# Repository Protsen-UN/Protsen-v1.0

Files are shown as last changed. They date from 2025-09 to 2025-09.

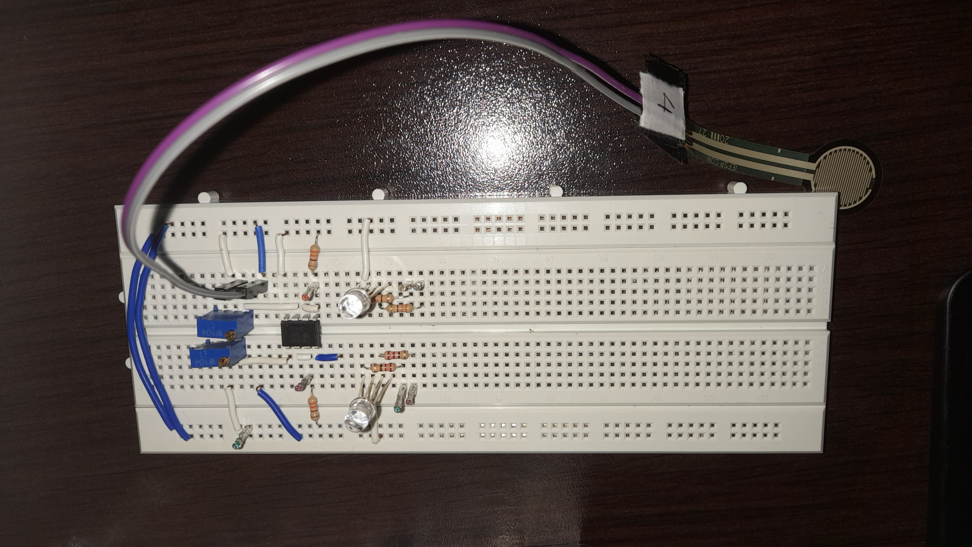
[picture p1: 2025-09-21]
Imagenes/MontajeRGB.jpg

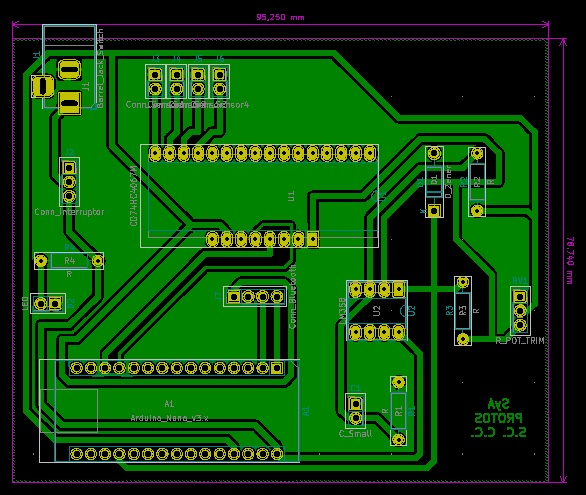
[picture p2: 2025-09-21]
Imagenes/DiseñoPCB.jpg

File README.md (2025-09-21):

# Protsen – Versión 2023

Este directorio contiene los avances y entregables del año **2023** del proyecto **Protsen**, desarrollado por el grupo estudiantil **Protos UN** de Bioingeniería en la Universidad Nacional de Colombia.

El enfoque de esta versión fue **construir y validar un sistema experimental con modelos anatómicos impresos en 3D y sensores FSR**, para analizar la presión ejercida por protuberancias óseas en un muñón.

---

## 📂 Estructura de carpetas

- **3D-Models/**  
  Contiene los modelos CAD y STL de la versión 2023.  
  - Variaciones de **cabeza del peroné (fibular head)**.  
  - Modelos de **tibia lateral y medial**.  
  - Variantes de la **tuberosidad tibial**.  
  - `Printing stump.stl`: muñón completo para impresión 3D.  
  - Archivos `.ipt` para edición paramétrica en Autodesk Inventor.  

- **Documentación/** *(si aplica)*  
  Reportes, protocolos de calibración y metodologías utilizadas en 2023.  

- **Electrónica/** *(si aplica)*  
  Esquemas, código o configuraciones empleadas para integrar los sensores FSR.  

---

## 🎯 Objetivos de la Versión 2023

- **Modelado CAD anatómico** de protuberancias óseas con diferentes dimensiones (flat, 5mm, 10mm, 15mm).  
- **Fabricación aditiva (impresión 3D)** del muñón y sus variaciones.  
- **Integración de sensores FSR** en zonas críticas del muñón.  
- **Calibración experimental** de los sensores para medir la presión.  
- **Documentación técnica** para futuras versiones del proyecto.  

---

## 🛠️ Requisitos técnicos

- **Software CAD**: Autodesk Inventor o Fusion 360 para editar `.ipt`.  
- **Impresora 3D** compatible con `.stl`.  
- **Material de impresión**: PLA / ABS recomendado.  
- **Sensores**: FSR calibrados para registrar presión.  

---

## 👩‍🔬 Grupo de investigación

Proyecto desarrollado por el grupo estudiantil **Protos UN – Bioingeniería**,  
Universidad Nacional de Colombia.  

---

## 📜 Licencia

Este proyecto se distribuye bajo la licencia **MIT**.  
Puedes usar, modificar y compartir libremente, dando el crédito correspondiente al grupo **Protos UN**.

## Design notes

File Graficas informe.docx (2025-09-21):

SENSOR 1

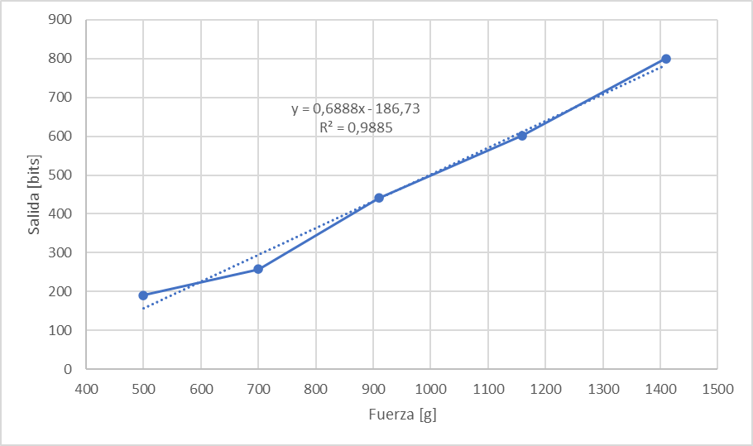
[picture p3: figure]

SENSOR 2

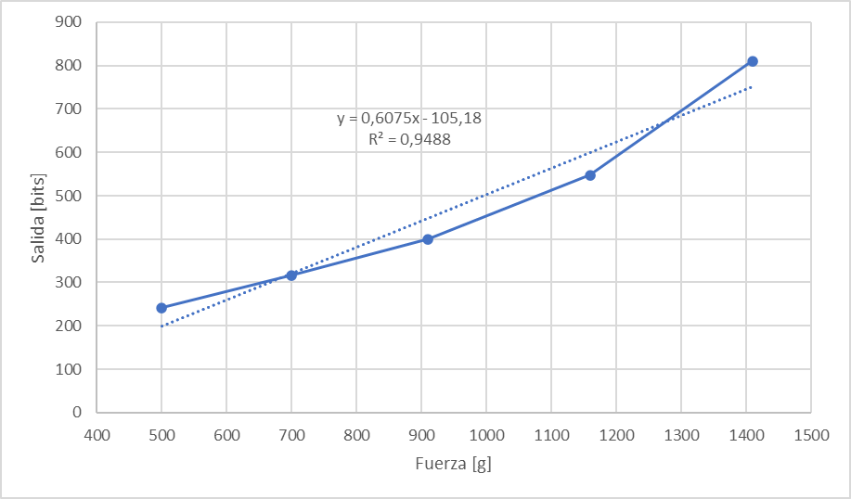
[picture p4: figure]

SENSOR 4

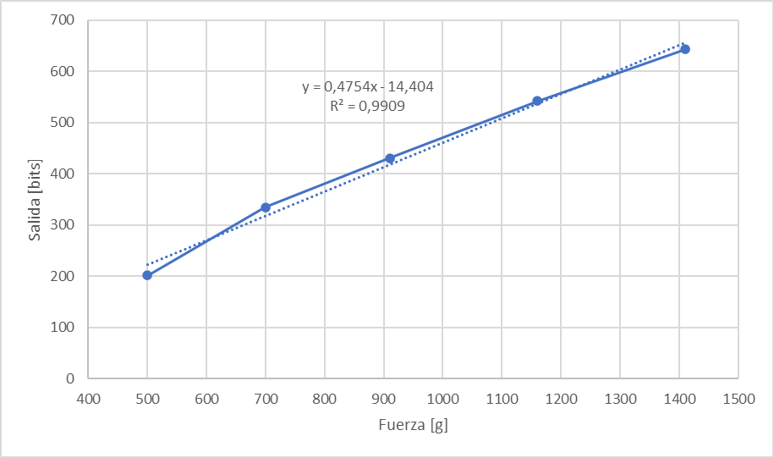
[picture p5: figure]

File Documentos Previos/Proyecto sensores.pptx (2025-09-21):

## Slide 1

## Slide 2

Proyecto Sensores

Y.F.Alpala - E.Cuadros - J.S.Daleman – N.Prieto

Ingeniería mecatrónica y mecánica
Departamento de ingeniería mecánica y mecatrónica
Facultad de ingeniería Universidad
Nacional de Colombia Bogotá,
Colombia
2023

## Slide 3

Problemática y solución

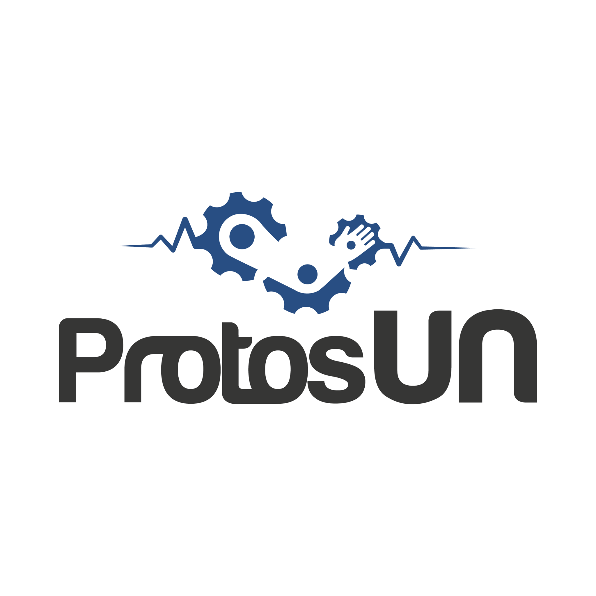
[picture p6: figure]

- Las prótesis son creadas de forma genérica por lo que al no acoplarse perfectamente al muñón pueden crear incomodidades.
- Es necesario modificar las prótesis para evitar que le tallen al usuario.
- Se plantea un sistema que detecte las fuerzas ejercidas sobre el muñón para facilitar su adaptación al usuario.

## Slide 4

Elementos necesarios

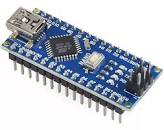
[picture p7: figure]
Arduino Nano Atmega Mini Usb V3.0
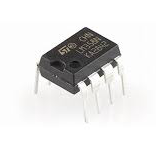
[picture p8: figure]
LM358 Amplificador Operacional lm358 Circuito Integrado – Arca Electrónica
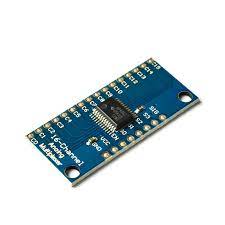
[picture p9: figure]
Modulo Multiplexor Digital/Analógico 16 Canales CD74HC4067 - Electronilab
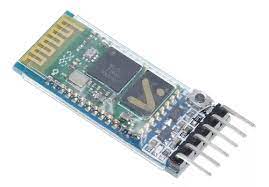
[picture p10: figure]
Modulo Transceptor Rf Bluetooth Hc-05 Arduino Pic Otros
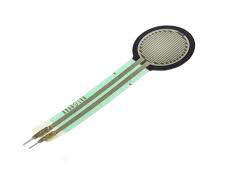
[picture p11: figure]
SENSOR DE FUERZA RESISTIVO FSR402
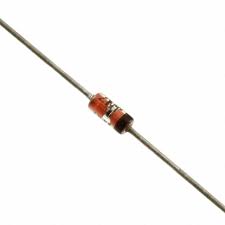
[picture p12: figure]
1N4931 Microchip Technology | Productos semiconductores discretos | DigiKey

Facultad Ancízar Sans Itálica 9 pt
Sede Ancízar Sans Itálica 9 pt

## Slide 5

Circuito electrónico

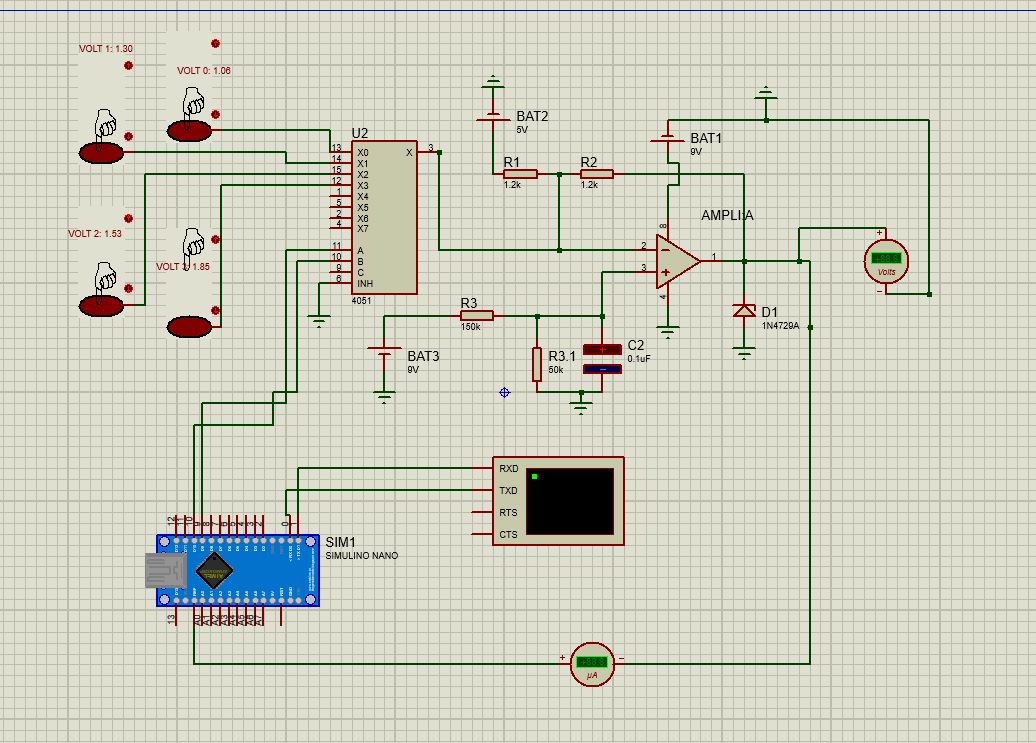
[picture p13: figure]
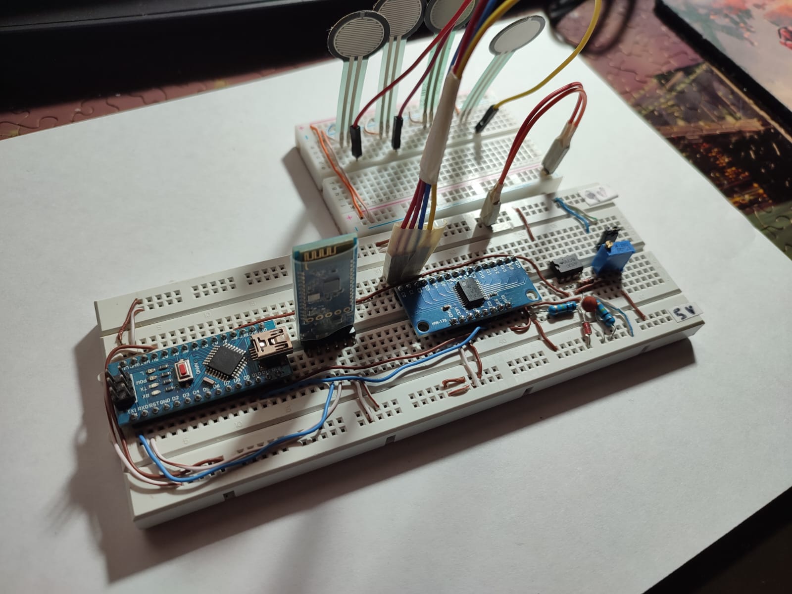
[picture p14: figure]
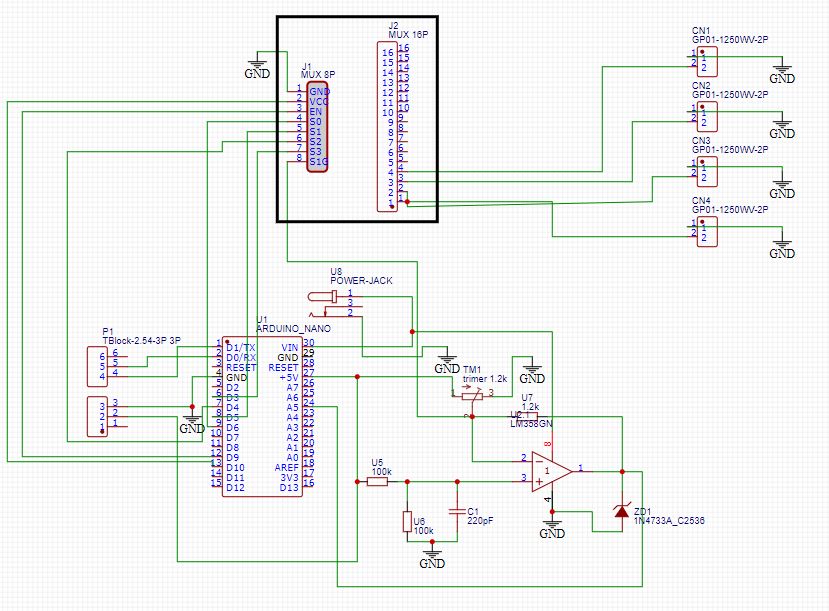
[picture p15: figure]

Facultad Ancízar Sans Itálica 9 pt
Sede Ancízar Sans Itálica 9 pt

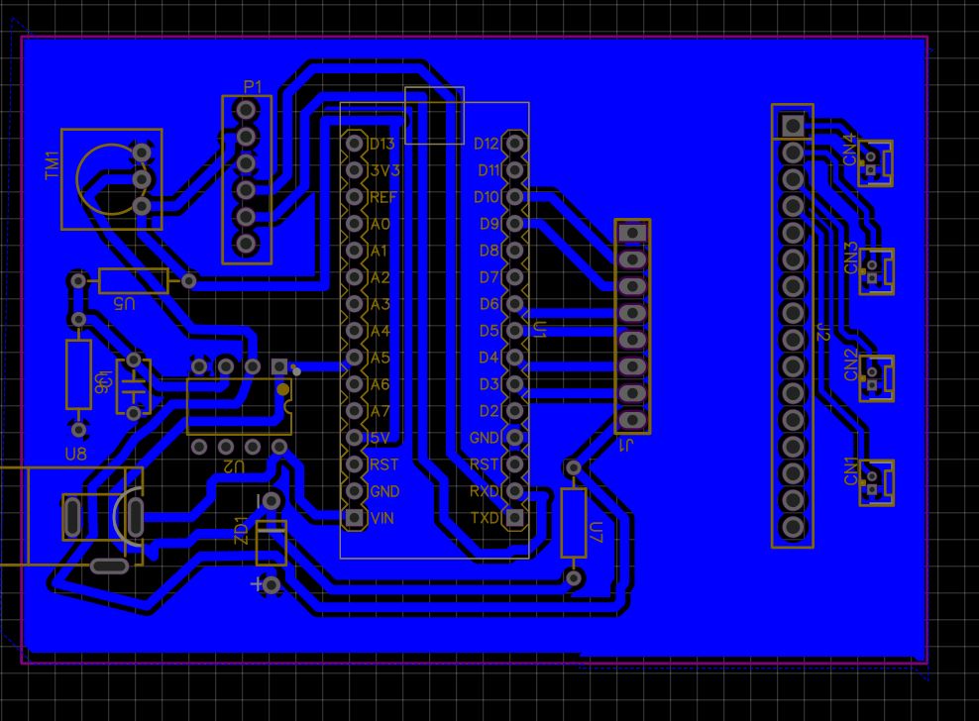
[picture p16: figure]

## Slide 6

Interfaz grafica

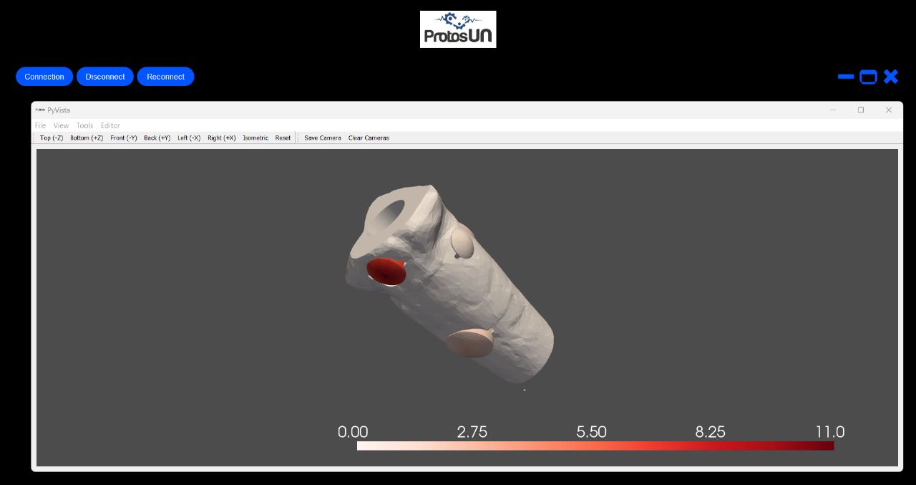
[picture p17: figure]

Facultad Ancízar Sans Itálica 9 pt
Sede Ancízar Sans Itálica 9 pt

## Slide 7

Referencias
[1] “Ajuste psicosocial en pacientes amputados: La psicolog ́Ia en el contexto sanitario.”https://www.binasss.sa.cr/bibliotecas/bhp/cupula/v31n2/art02.pdf ,
consultado: 2023-06-28.
[2] V. A, USO DE SENSORES DE FUERZA RESISTIVOS PARA MEJORAR LA COMODIDAD EN PR ́OTESIS PARA EXTREMIDADES DE ANIMALES. UNIVERSIDAD SAN FRANCISCO DE QUITO USFQ, 2021.
[3] “Fsr 402 datasheet,” https://www.trossenrobotics.com/productdocs/2010-10-26-DataSheet-FSR402-Layout2.pdf, consultado: 2023-05-08.

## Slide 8

Gracias

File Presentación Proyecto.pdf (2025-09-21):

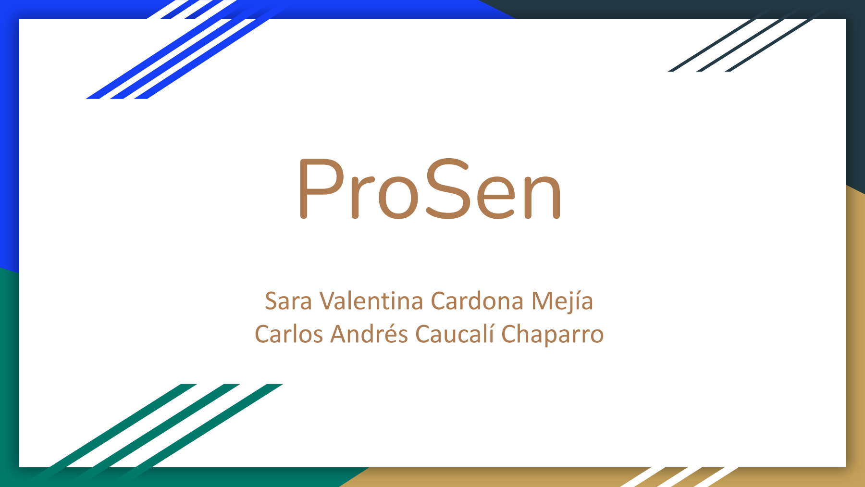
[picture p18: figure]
ProSen; Sara Valentina Cardona Mejía Carlos Andrés Caucalí Chaparro

# Planteamiento

- Continuación del proyecto de Protos UN → Medición de la presión en ciertos puntos en un modelo 3D de un muñón de pierna para simular la presión que ejerce una prótesis de pierna sobre el muñón.

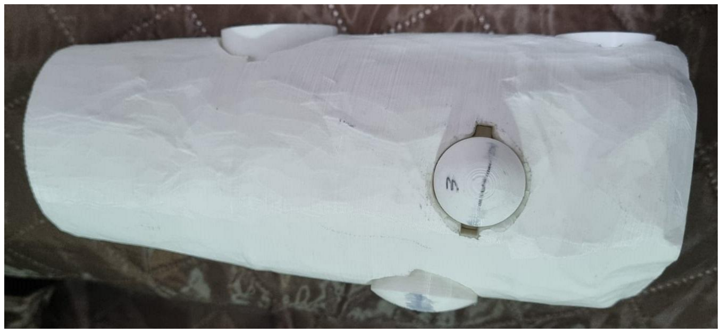
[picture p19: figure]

- Circuito en protoboard.
- Modelo 3D del muñón.
- Programa de la interfaz.

# Propuesto vs Logrado

- Diseño e implementación del circuito en una PCB.
- Calibración de los sensores en el muñón.
- Implementación de la información obtenida de la calibración en la interfaz gráfica del modelo 3D del muñón (comunicación en tiempo real de lo obtenido por los sensores con el
modelo | 3D | para | su | correcta
visualización).
- Diseño e implementación de una PCB, sin embargo, el tamaño se puede reducir.
- Calibración de los sensores, sin embargo, el procedimiento no fue el más adecuado.
- Implementación de la información obtenida de la calibración en la interfaz gráfica del modelo 3D del muñón, sin embargo, la comunicación en tiempo real presentó problemas.

# Problemas y Retos Presentados

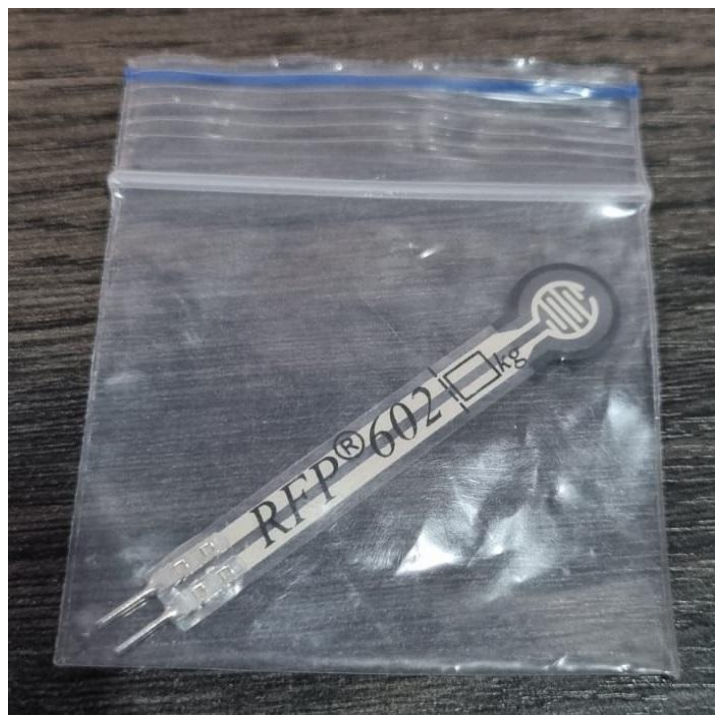
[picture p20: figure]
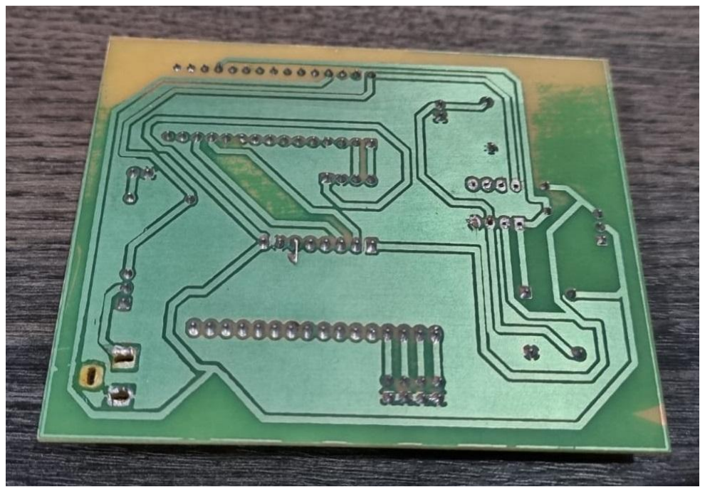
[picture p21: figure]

- La PCB quedó mal diseñada.
- El sensor RFP602 no funcionó.
- | La | lectura | de | los | canales | del
multiplexor presentó errores.
- El procedimiento para la calibración no fue el más adecuado.
- La comunicación por medio de bluetooth con el programa para generar la interfaz no fue efectiva.

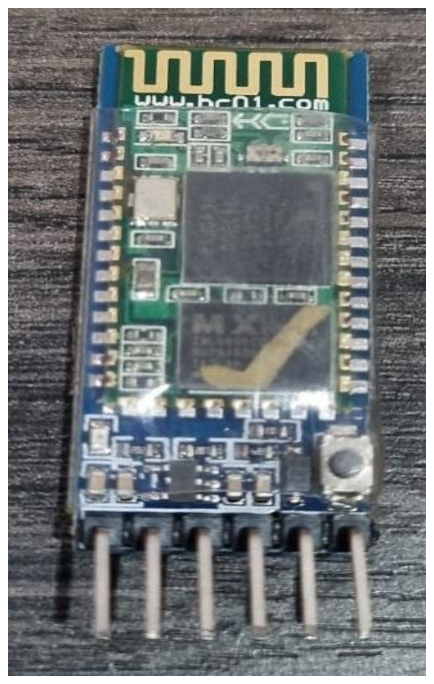
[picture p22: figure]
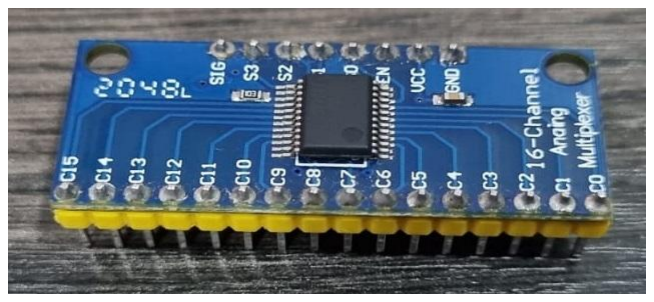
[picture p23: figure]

# PCB

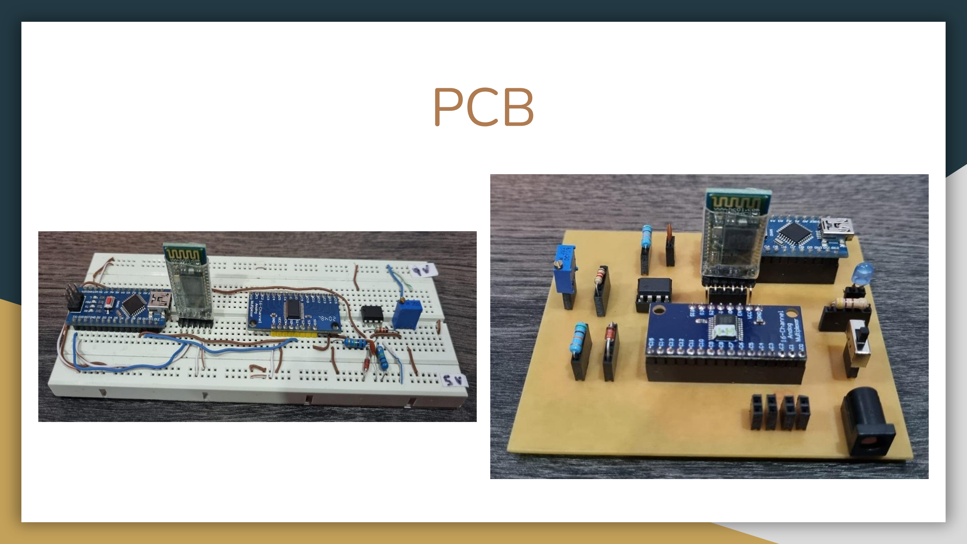
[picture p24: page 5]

# Calibración

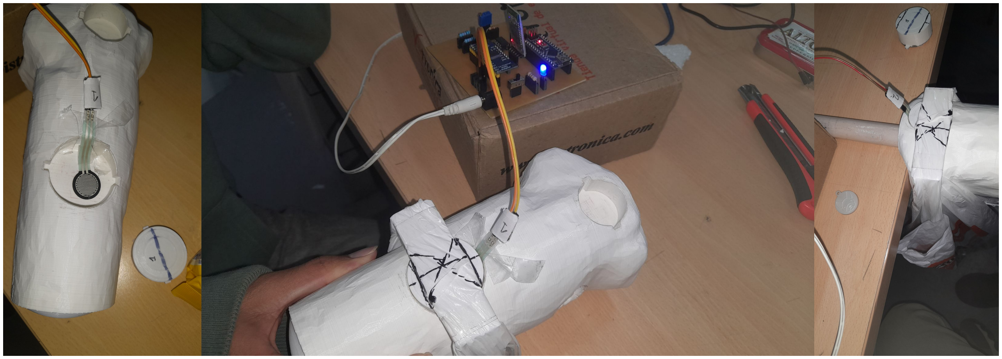
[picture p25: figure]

# Calibración

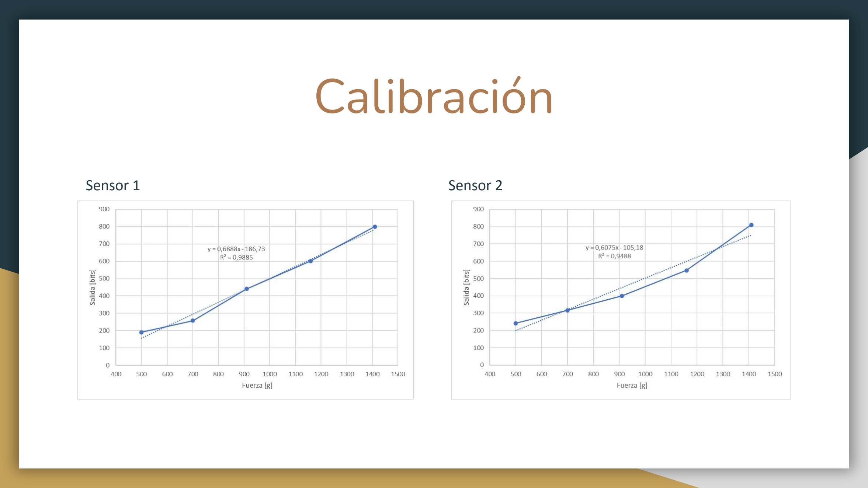
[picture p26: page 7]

Sensor 1 | Sensor 2

# Calibración


Sensor 3 | Sensor 4

# Interfaz


# Interfaz


# Montaje Circuito con RGB


20 N

0 N

# Costos

Implemento | Precio (COP)
PCB | $50.000
Componentes electrónicos | $50.000
Cable Arduino | $8.000
Papelería | $5.000
Total | $113.000

# A futuro…


- Reducir el tamaño de la PCB y añadir más sensores.
- Rediseñar el modelo 3D del muñón para realizar de manera correcta la calibración de los sensores.
- Revisar la comunicación en tiempo real de lo obtenido por los sensores con la interfaz.

# Gracias

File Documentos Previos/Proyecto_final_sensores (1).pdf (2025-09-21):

# Sistema de lectura de puntos de presion para ´

adecuacion de pr ´ | otesis de pierna ´

1

st Juan Sebastian Daleman Martinez
Universidad Nacional de Colombia Bogota, Colombia
jdaleman@unal.edu.co

2

nd Nicolas Prieto ´
Universidad Nacional de Colombia Bogota, Colombia
nprietos@unal.edu.co

3

rd Yuli Fernanda Alpala
Universidad Nacional de Colombia Bogota, Colombia
yalpalac@unal.edu.co

4

th Eduardo Cuadros Montealegre
Universidad Nacional de Colombia Bogota, Colombia
ecuadrosm@unal.edu.co
I. RESUMEN
En este trabajo, se presenta el desarrollo de un sistema de monitoreo de fuerzas portatil que utiliza sensores de fuerza ´ resistivos (FSR). El sistema incluye una interfaz de usuario que muestra en tiempo real un modelo 3D del munõn, donde se ´ representan las fuerzas aplicadas mediante un mapa de calor. Este enfoque permite obtener informacion precisa y detallada ´ sobre las fuerzas ejercidas en el munõn durante el uso de ´ protesis. Al visualizar las fuerzas en el modelo 3D, se pueden ´
identificar areas de alta presi ´ | on y evaluar como var ´ | ían las
fuerzas en diferentes situaciones. Esta informaci ´ | on es esencial ´
para mejorar el diseno mec ˜ | anico de la pr ´ | otesis y lograr una ´
distribucion m ´ | as equilibrada de las fuerzas, reduciendo as ´ | í los
problemas de incomodidad y las posibles lesiones cutaneas. ´
Index Terms—FSR, Protesis, Z ´ | ocalo, Mu ´ | nõn, Interfaz, Sensores, ´
Fuerzas.

II. INTRODUCCION´

En la actualidad, las amputaciones de extremidades son una realidad en muchas personas de todo el mundo, estas representan un desafío significativo para la calidad de vida de las personas que lo experimentan. A menudo se requiere es
uso de las protesis para proporcionar una soluci ´ | on importante ´
para mejorar la funcionalidad y el bienestar de los individuos afectados. [1] Sin embargo, aunque se han proporcionado avances en la tecnología de protesis, muchos usuarios ´ experimentan problemas de incomodidad y dolor debido a
la mala distribucion de fuerzas en el z ´ | ocalo de la pr ´ | otesis. ´
Debido a esto se presentan diversos inconvenientes, como lesiones cutaneas, infecciones y otras complicaciones que ´ afectan negativamente la experiencia de los usuarios. [1]

Para abordar esta problematica, es necesario desarrollar ´
un monitoreo de fuerzas entre el zocalo de la pr ´ | otesis y el ´
munõn residual. Este sistema permitir ´ | ía extraer informacion´
valiosa para mejorar el diseno mec ˜ | anico de la pr ´ | otesis y ´
lograr un ajuste adecuado. Si se obtienen datos precisos sobre las fuerzas ejercidas en el munõn durante el uso de la ´
protesis, se puede evaluar de manera objetiva la distribuci ´ | on´
de fuerzas y detectar posibles puntos de presion excesiva o ´
areas problem ´ | aticas. Lo anterior es de gran importancia para ´

prevenir lesiones cutaneas, minimizar el dolor y mejorar la ´ comodidad general de los usuarios de protesis. ´

La importancia de mejorar el ajuste del encaje protesico ´ debe ser de gran importancia, pues esta tiene un impacto en la calidad de vida, la salud y el bienestar de las personas con amputaciones. Los encajes mal ajustados limitan la capacidad funcional y la participacion en actividades diarias. ´ Por ello, es crucial que se dediquen esfuerzos significativos para desarrollar enfoques innovadores que aborden este desafío clínico y mejoren la calidad de vida de las personas con amputaciones. Así pues, en este trabajo se presenta un prototipo de sistema de monitoreo de fuerzas portale, ´ utilizando sensores de fuerza resistivos, este cuenta con interfaz de usuario que muestra en tiempo real, un modelo
3D del munõn, las fuerzas aplicadas sobre ´ | este mediante ´
un mapa de calor, permitiendo así un analisis en periodos ´
de tiempos largos, el prototipo sera aplicado a la pr ´ | otesis ´
desarrollada por el grupo de investigacion ProtosUN de la ´ Universidad Nacional de Colombia.

III. MARCO TEORICO ´

A. Sensores FSR
Los sensores FSR son dispositivos usados comunmente para ´
la medicion de presi ´ | on o fuerza aplicada a una superficie (ver ´
Figura 1). Dichos sensores estan compuestos por una capa ´ delgada de material resistivo sensible a la presion que se ´ encuentra entre dos electrodos. Cuando se aplica una fuerza sobre el sensor, la capa resistiva se comprime y provoca un cambio en su resistencia electrica, la cual se puede medir para ´ hallar la magnitud de la fuerza aplicada.
B. Arduino
Arduino (ver Figura 2) es una plataforma de desarrollo tanto de software como de hardware. Esta compuesto por un microcontrolador y una placa de circuito impreso que permite programar dicho microcontrolador y así manejar dispositivos electronicos de manera sencilla. Para este nos basamos en el ´ diseno encontrado en [2] ˜


Figure 1: Sensor FSR


Figure 2: Arduino Nano

C. Interfaz en python

Python es un lenguaje de programacion de alto nivel y ´
facil de usar, adem ´ | as cuenta con una amplia variedad de ´
bibliotecas y frameworks que aumentan sus posibilidades.
1) PyVista: Usada para visualizacion y an ´ alisis de datos en ´ 3D.
2) PyQt5: Desarrollo de interfaz grafica donde se presenta ´ la figura 3D.
3) NumPy: Manejo de todo lo relacionado con operaciones matematicas y matrices. ´
4) Serial: Manejo y comunicacion con el puerto serial del ´ arduino.

IV. METODOLOGÍA

A. Circuito electronico ´

Para el acople de los sensores FSR con el arduino era
necesario acondicionar adecuadamente la senal adem ˜ | as de al ´
limitarse que se deseaba usar un solo modulo de ADC para usar la menor cantidad de recursos del arduino y necesitar un solo circuito de acondicionamiento. Se implemento un multeplexor para seleccionar la senal que es sensada, un ˜ amplificado operacional para acondicionar la senal y un diodo ˜ zener como proteccion de la entrada del arduino.(Ver figura 3) ´


Figure 3: Circuito de acondicionamiento de la senal . ˜

EL amplificador operacional es un LM358 en una configu-racion de restador, las resistencia R1 se implemento como un ´ trimmer para la calibracion del circuito para obtener el mejor ´ punto de operacion posible. El multiplexor es un HP4067 el ´ cual permite recorrer uno por uno los sensores e ir midiendo sus valores. Se tiene el diodo zener que es un 1N4729 que
sirve para tener una tension en la salida m ´ | axima en la entra ´
del arduino de 5V y cualquier corriente anomala sea rechazada ´ por la entrada del arduino. Por ultimo un modulo Tx-Rx el cual en la implementacion se coloco como un modulo bluetooth hc- ´
05 para hacer la conexion con el computador que recibir ´ | a los ´
datos como se puede ver mejor en la figura 4.


Figure 4: Circuito de acondicionamiento de la senal implementado en una ˜ protoboard.

B. Programacion arduino ´
Para el desarrollo del codigo se destino que se usar ´ | ían 4
sensores para esto el multiplexor solo necesita dos pines de control, se usaria el ADC del aduino por el PIN A0 y los datos se transmitirían al computador por comunicacion serial. ´ Ademas de que los datos se van almacenando en una cadena ´

de texto la cual es transmitida cada segundo.

El codigo final se dividi ´ | o en dos partes uno usado para ´
la calibracion de cada sensor y otro que seria el de ´ funcionamiento donde se muestrean todos los sensores y se envía la informacion. ´


Figure 5: Programa implementado en el arduino Nano.

C. Calibracion de sensores RFS ´
Para la calibracion de los sensores RFS primero se ´ acomodo el cero del circuito al mejor punto posible siendo este punto en un valor de bits 260, luego teniendo en cuenta que el fabricante de los sensores dice que estos operan entre un rango de 0-12N. Esta fuerza podría generar se al colocar sobre una superficie plana y horizontal 1.2 Kg, por lo cual se hicieron 12 bolsas de arroz cada uno con un peso de 100 gramos (los patrones se hicieron usando una gramera) para lograr el peso completo. [3]

Por ultimo se experimento con cada sensor poniendo ascendentemente los pesos y luego descendente. Por ultimo se hicieron pruebas aleatorias con los pesos obteniendo un comportamiento lineal como lo indica el fabricante pero con un rango de 11N solamente. Siendo la curva ideal una muy buena aproximacion para estos sensores. ´

D. Desarrollo interfaz grafica ´
La interfaz grafica esta dividida por tres partes: la barra ´ de conexion, la barra de acciones y un mapa de calor sobre ´ el modelo del munõn en donde se encuentran los sensores ´ distribuidos (ver figura 6).
Para la parte de conexion de se creo un c ´ | odigo el cual ´
verifica los puertos bluethoot utilizados en el computador y verifica en cada uno hasta encontrar uno que tengo un frame de datos ”Sensor1:”, si no encuentra ninguno desplegara un mensaje para el usuario de error de conexion. Al encontrar el ´ dispositivo guarda los datos en listas y los organiza para su posterior uso.

Para la parte del mapa de calor se creo un programa que modifica los valores de malla de un archivo .STL como base y segun los datos que reciba de la conexion ira ´ actualizando la grafica mostrada al usuario. ´

Para la barra de acciones de usuario se crearon botones para ampliar, cerrar y minimizar la pantalla.


Figure 6: Interfaz grafica obtenida con dos ventanas independientes. ´

E. Plano para PCB
Una vez se termino el circuito y se prob ´ | | o en protoboard, se ´
hizo el diseno y la posterior fabricaci ˜ | | on del circuito impreso. ´
En cuanto al diseno se us ˜ | o el programa EasyEDA. ´

Disenando el plano se tuvieron ciertas dificultades con ˜
la organizacion, ya que la placa deb ´ | | ía tener el menor tamanõ
posible. Teniendo en cuenta esto, se decidio cambiar un poco ´ el codigo en Arduino para ahorrar distancias en los buses. De ´ esta manera, la salida del amplificador ya no llegaría al pin
A0 del Arduino, sino al A5. Tambien se decidi ´ | o usar el pin ´
D10 como salida de 5 V para la alimentacion del multiplexor, ´
ya que este no consume m ´ | as de ´ | 100mA (capacidad maxima ´
para pines digitales del Arduino). El resultado del diseno se ˜ puede ver en la Figura 7.


Figure 7: Esquematico de circuito impreso ´

V. RESULTADOS
Como ya se establecio durante la introducci ´ | on de este ´
informe, el objetivo principal era la creacion de un sistema ´ que midiera las fuerzas ejercidas por el zocalo sobre el ´ munõn, objetivo que fue cumplido en su totalidad con los ´ requisitos propuestos por el grupo de investigacion, logrando ´ una calibracion de sensores exitosa con mediciones que ´
presentan buena precision. En la secci ´ | on de desarrollo se ve ´
el cumplimiento de los objetivos adicionales correspondientes a realizar una interfaz que resulte entendible para gente sin
conocimiento en el area de la ingenier ´ | ía, haciendo que esta
sea mas visual y entendible mediante la muestra del modelo
3d del munõn, de manera adicional, la PCB dise ´ | nada tambi ˜ | en´
cumple con el requerimiento de tamano ya que cabe dentro ˜ de orificio creado para el modelo real del munõn. ´

Como resultados para aprendizaje del grupo, se tiene un mejor entendimiento en el proceso de calibracion de sensores y ´ practica en el diseno de sistemas que permitan el uso de varios ˜ de estos, se vio de manera mas practica la adquisicion de datos ´
para multiples sensores mediante un Arduino. Se aprendi ´ | ó
sobre la integracion y comunicaci ´ | on de datos entre los dis- ´
positivos usando la comunicacion serial de Arduino fuera de ´ su software propio y sobre las dificultades de la creacion de ´
interfaces graficas que implementen la visualizaci ´ | on de datos ´
en 3d actualizada de manera constante.

VI. MEJORAS POSIBLES

- Crear un circuito completo que no use modulos sino ´ solo elementos SMD (un chip CC2540 para transmision´ bluetooth con su circuito de funcionamiento, un LM358 SMD, el multiplexor HP4067 que este integrado en la PCB) y cambiar el arduino por un microcontrolador
mas peque ´ | no que tenga los recusos necesarios (4 salidas ˜
digitales, 1 ADC y pines RX y TX).
- Uso de una bateria de polimero de litio recargable con su circuito de potencia para autonomía del circuito.
- incluir botones de reset y encedido/apagado
- Aumentar el numero de sensores usados de 4 a 8 o dado ´ el caso incluso a los 16 que soporta el multiplexor
- Integracion de las dos ventanas de la interfaz gr ´ | afica ´
- Crear una barra de menu donde puedan verse gr ´ | aficas de ´
las fuerzas cambiando en el tiempo.
- Mejorar la parte estetica de la interfaz gr ´ | afica. ´

VII. CONLUSIONES
- El desarrollo e implementacion de un sistema de mon- ´ itoreo continuo y en tiempo real de las fuerzas en una
protesis para extremidades inferiores es una contribuci ´ | | | | | | on´
significativa para mejorar la calidad de vida de los usuarios de protesis. ´
- La implementacion de una forma gr ´ | afica para mostrar los ´
datos tomados de sensores permite que la informacion´ pueda ser entendida mas facilmente por diferentes tipos ´ de usuarios.

REFERENCES

[1] “Ajuste | | psicosocial | en | | pacientes | amputa-
dos: | La | psicologÍa | en | el | contexto | sanitario.”
https://www.binasss.sa.cr/bibliotecas/bhp/cupula/v31n2/art02.pdf | ,
consultado: 2023-06-28.
[2] V. A, USO DE SENSORES DE FUERZA RESISTIVOS PARA MEJORAR LA COMODIDAD EN PROTESIS PARA EXTREMIDADES DE ANI- ´ MALES. UNIVERSIDAD SAN FRANCISCO DE QUITO USFQ, 2021.
[3] “Fsr 402 datasheet,” https://www.trossenrobotics.com/productdocs/2010-10-26-DataSheet-FSR402-Layout2.pdf, consultado: 2023-05-08.

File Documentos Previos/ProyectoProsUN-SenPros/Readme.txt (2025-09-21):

Solo es necesario tener el dispossitivo conectado al PC y ejecurar el .exe

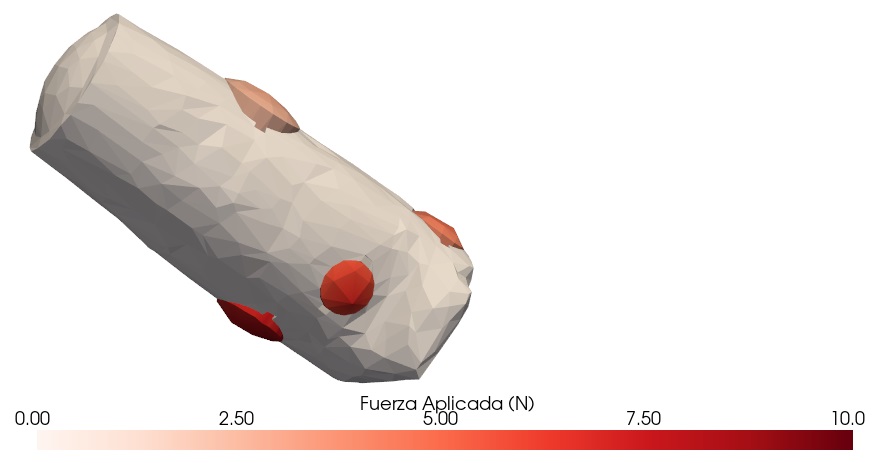
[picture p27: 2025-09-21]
Imagenes/Modelo3D.jpg

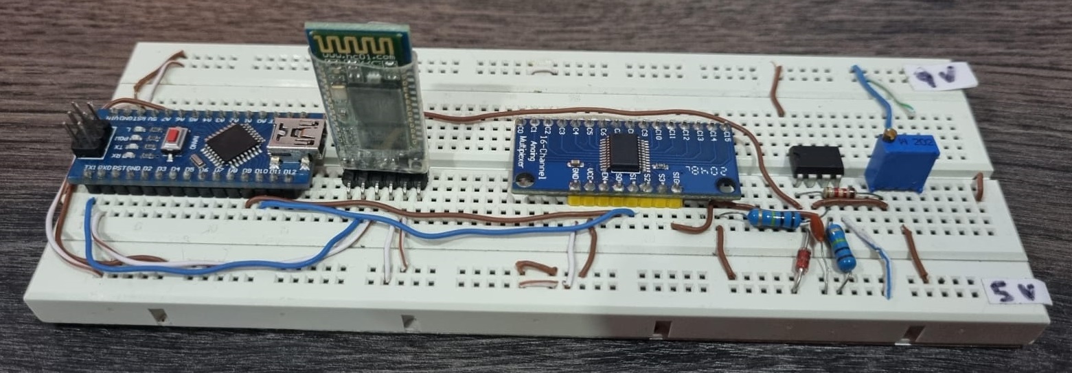
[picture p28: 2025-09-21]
Imagenes/CircuitoProtoboard.jpeg

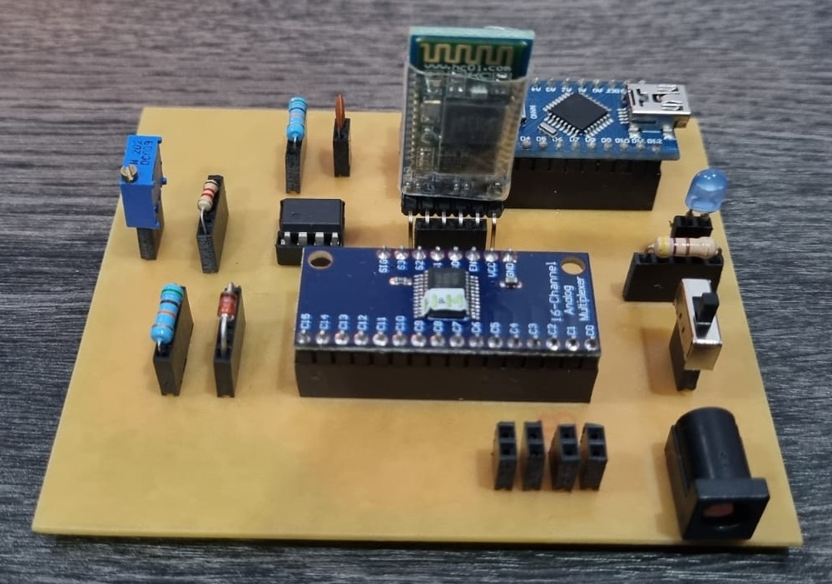
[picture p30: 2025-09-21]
Imagenes/CircuitoPCB.jpeg

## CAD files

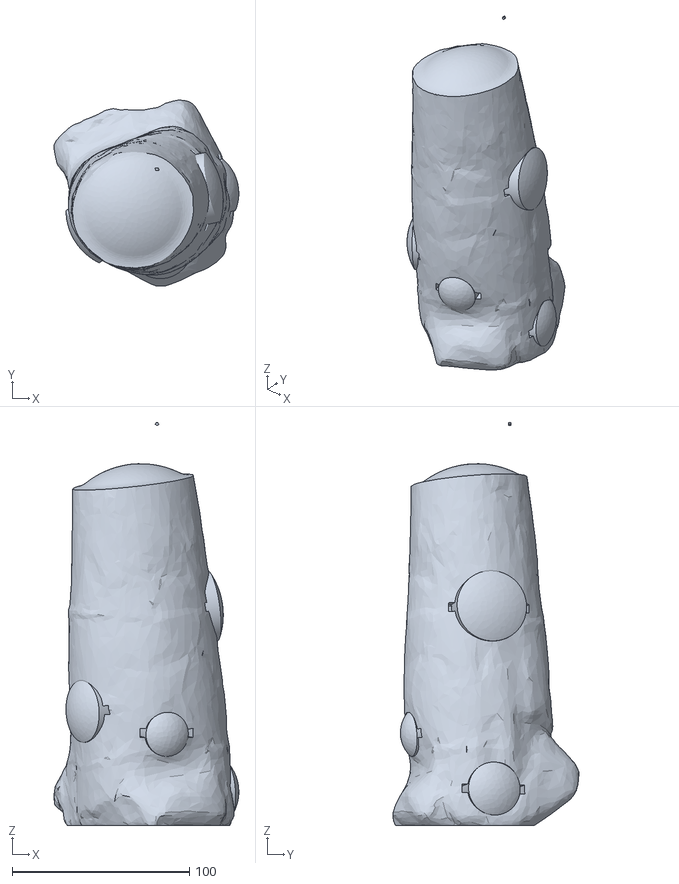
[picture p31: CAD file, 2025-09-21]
Documentos Previos/ProyectoProsUN-SenPros/MallaSimpl.stl
104.2 x 105.0 x 227.4

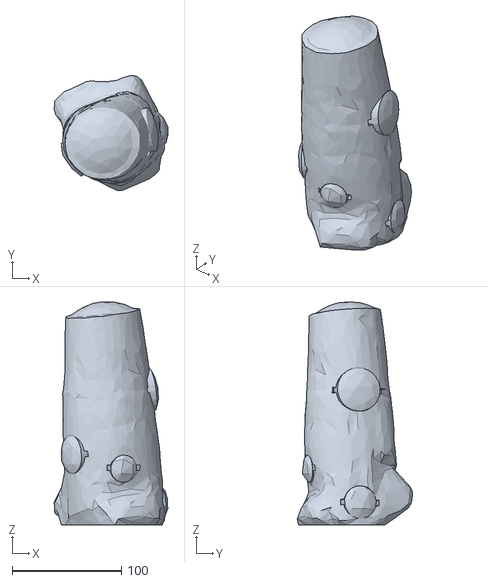
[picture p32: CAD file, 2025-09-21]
Interfaz Final/Sources/MallaSTL-sept1.stl
104.0 x 105.7 x 204.1

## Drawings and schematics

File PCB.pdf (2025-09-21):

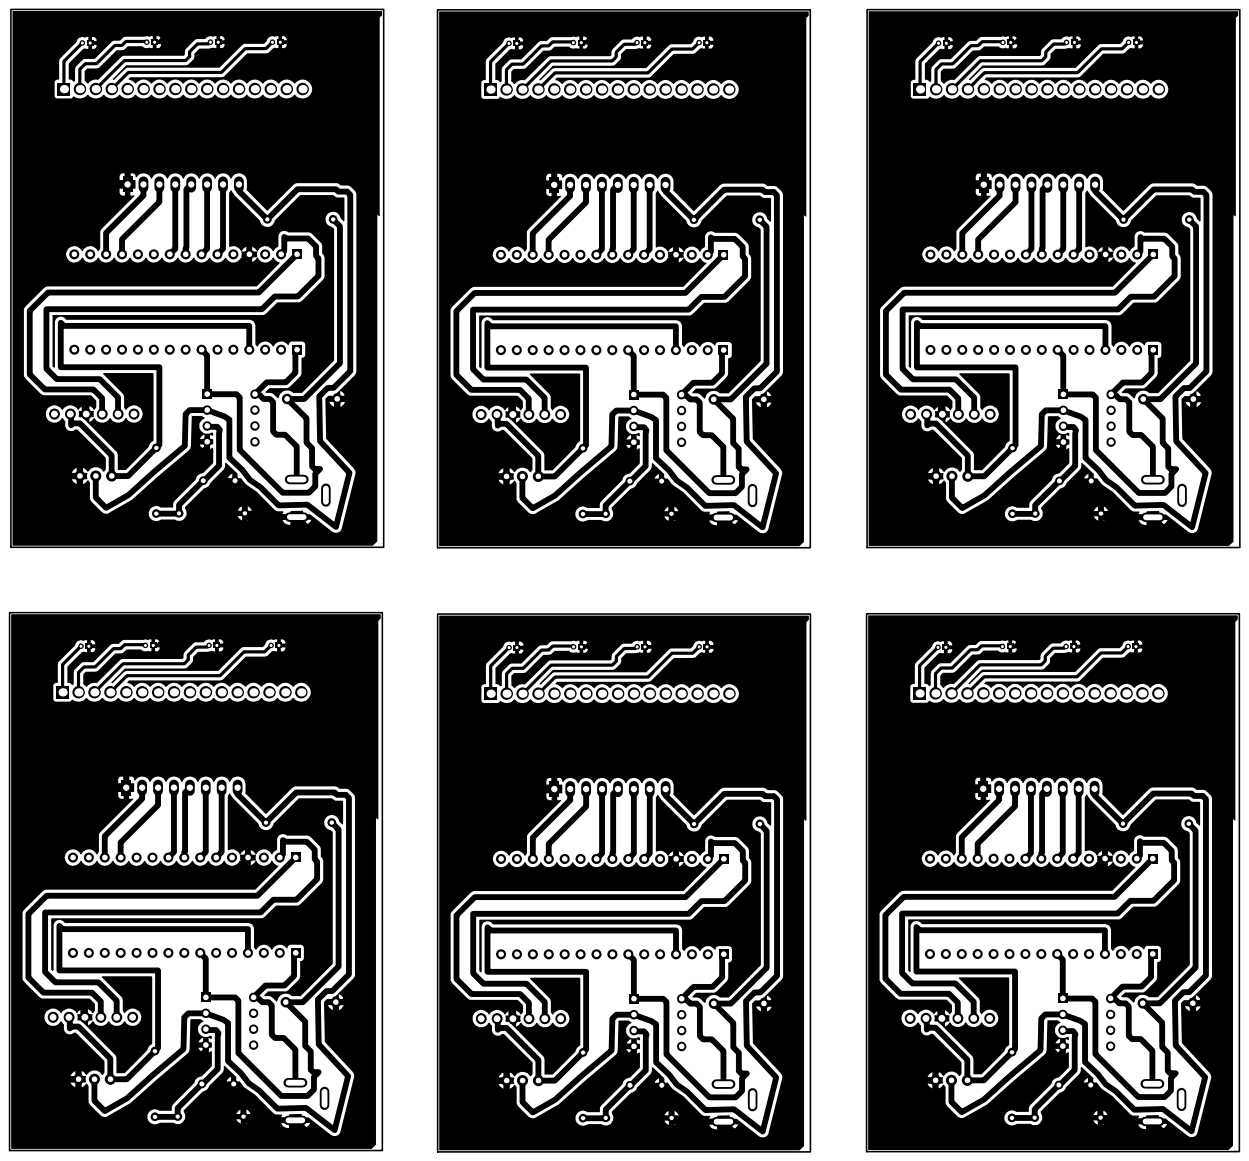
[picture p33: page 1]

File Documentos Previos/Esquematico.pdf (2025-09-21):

10 10 11 11 12 12 13 13 14 14 15 15 16 16

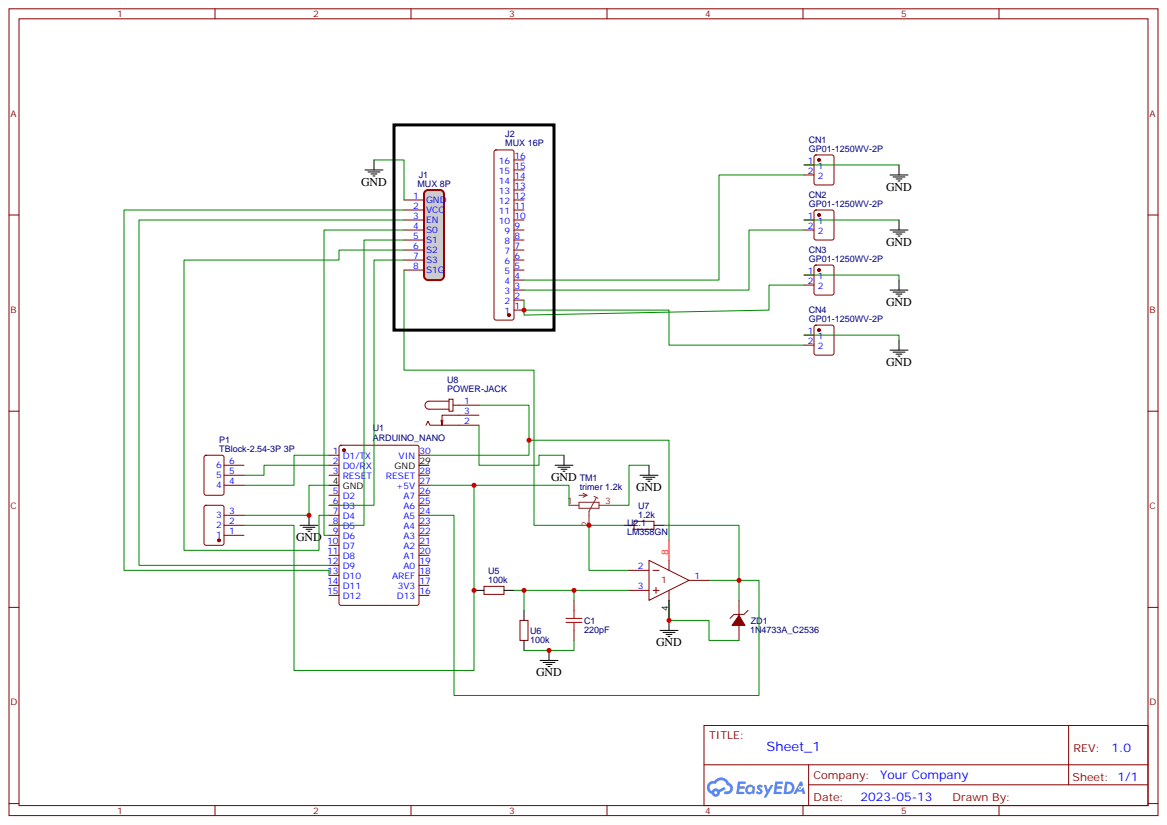
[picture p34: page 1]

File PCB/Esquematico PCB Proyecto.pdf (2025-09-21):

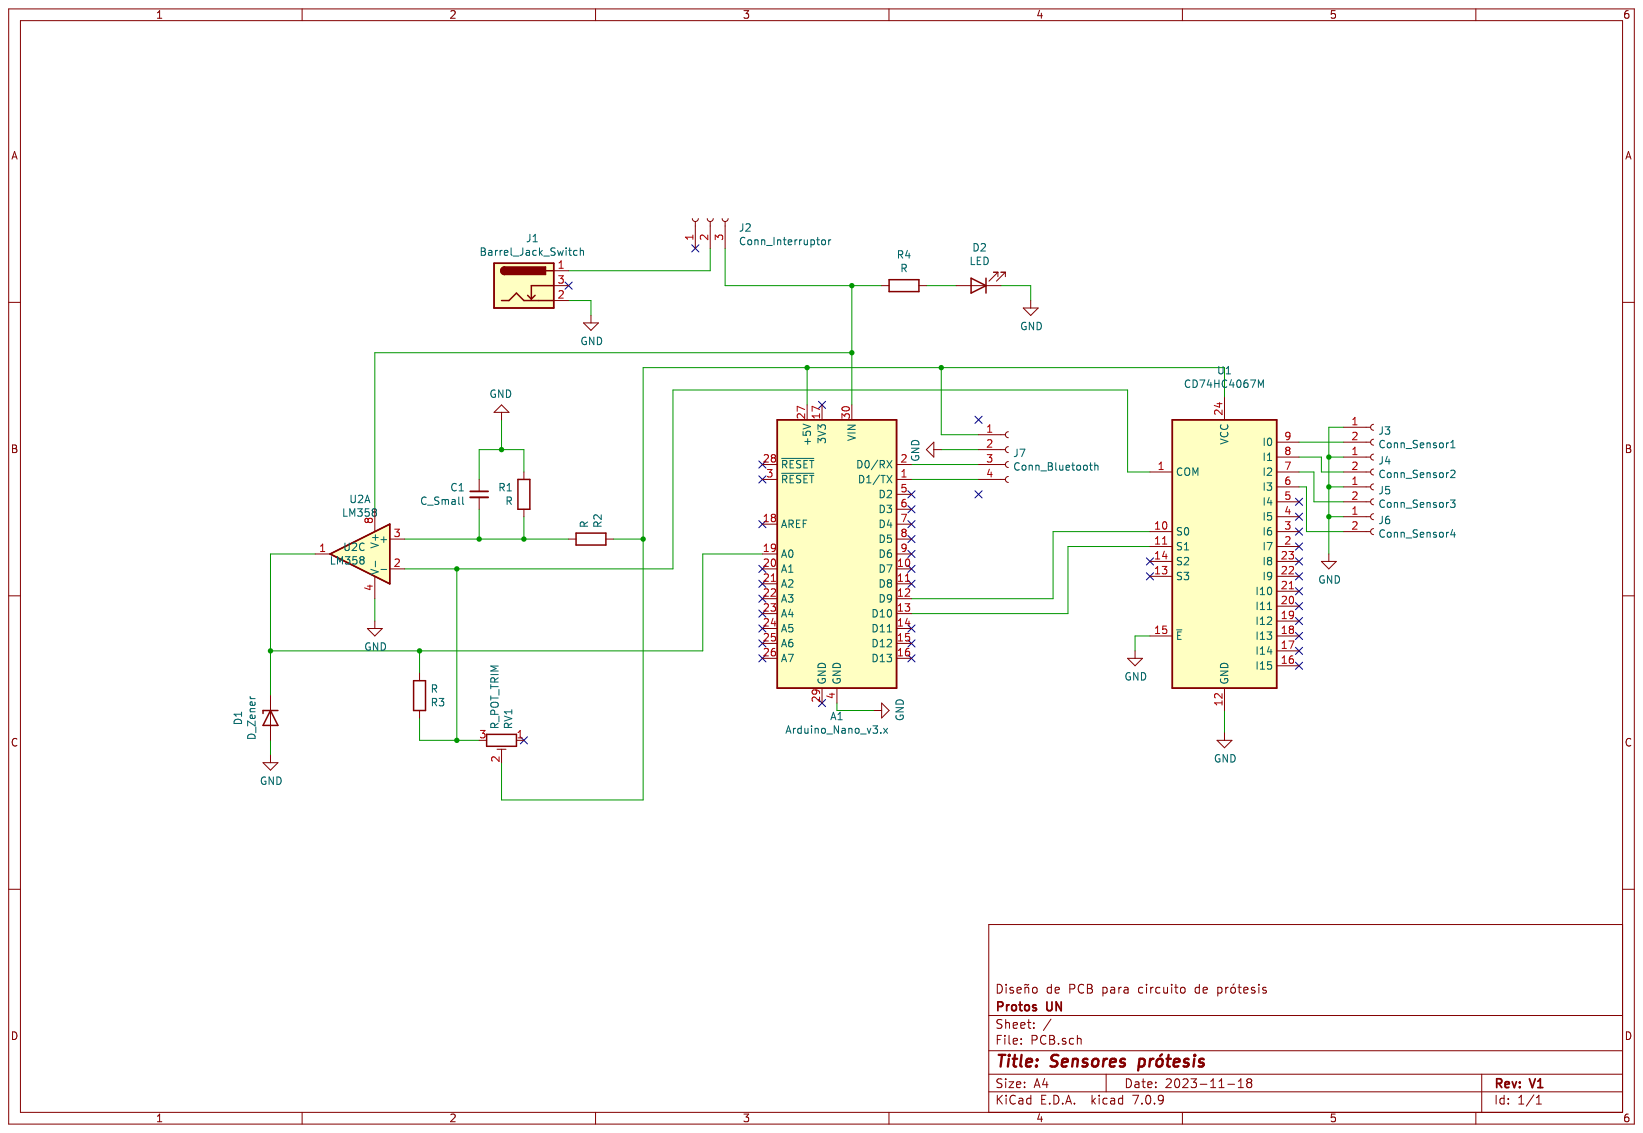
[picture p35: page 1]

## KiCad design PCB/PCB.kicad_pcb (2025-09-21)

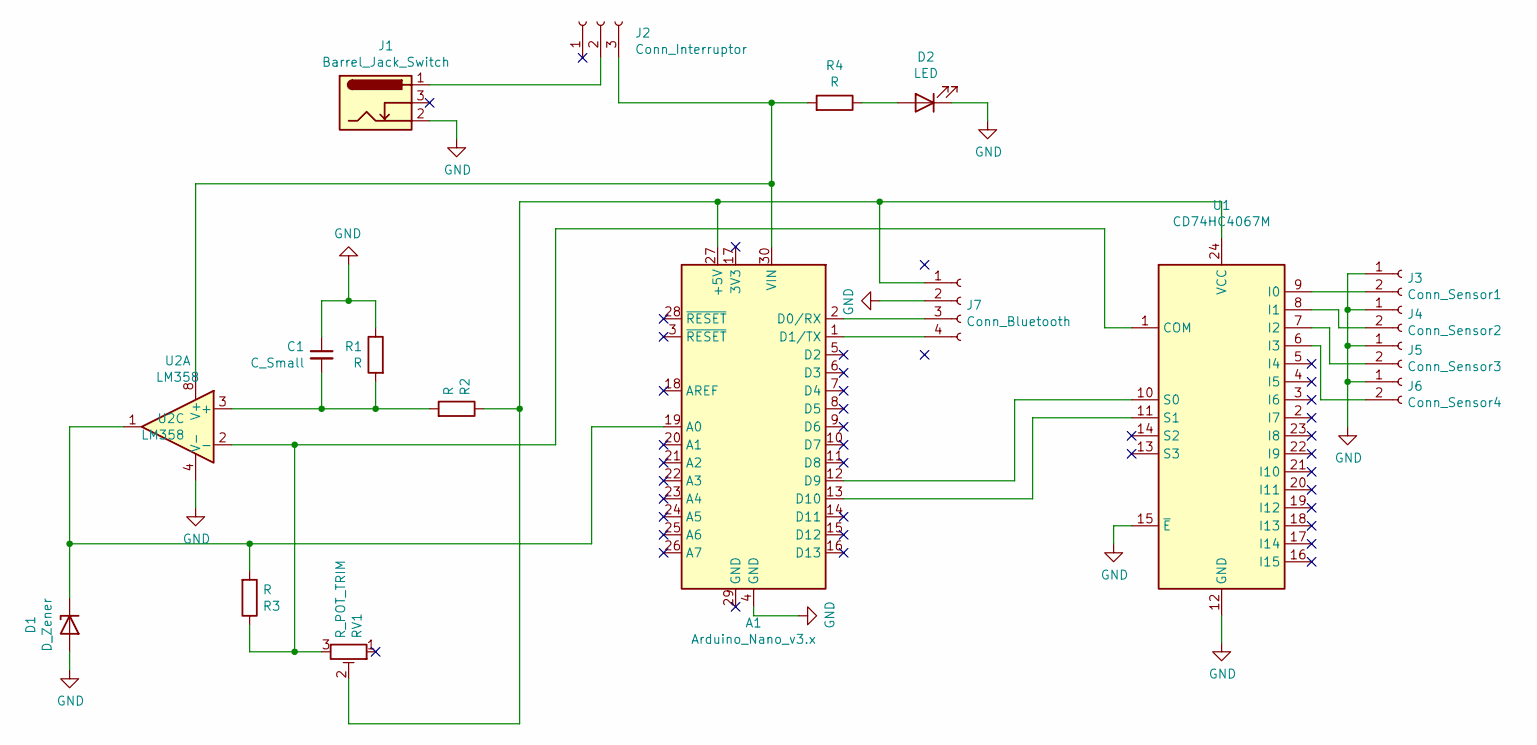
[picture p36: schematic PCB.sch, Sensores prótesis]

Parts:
A1: Arduino_Nano_v3.x; Arduino_Nano
C1: C_Small; PinSocket_1x02_P2.54mm_Vertical
D1: D_Zener; D_A-405_P10.16mm_Horizontal
D2: LED; PinSocket_1x02_P2.54mm_Vertical
J1: Barrel_Jack_Switch; BarrelJack_Horizontal
J2: Conn_Interruptor; PinSocket_1x03_P2.54mm_Vertical
J3: Conn_Sensor1; PinSocket_1x02_P2.54mm_Vertical
J4: Conn_Sensor2; PinSocket_1x02_P2.54mm_Vertical
J5: Conn_Sensor3; PinSocket_1x02_P2.54mm_Vertical
J6: Conn_Sensor4; PinSocket_1x02_P2.54mm_Vertical
J7: Conn_Bluetooth; PinSocket_1x04_P2.54mm_Vertical
R1, R2, R3, R4: R; R_Axial_DIN0207_L6.3mm_D2.5mm_P10.16mm_Horizontal
RV1: R_POT_TRIM; PinSocket_1x03_P2.54mm_Vertical
U1: CD74HC4067M; DIP-24_W15.24mm_LongPads
U2: LM358; DIP-8_W7.62mm_Socket_LongPads

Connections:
GND: A1.4 (GND), C1.1, D1.2 (A), D2.1 (K), J1.2, J3.1, J4.1, J5.1, J6.1, J7.2, R1.1, U1.12 (GND), U1.15 (~E), U2.4 (V-)
unnamed: A1.1 (D1/TX), J7.4
unnamed: A1.2 (D0/RX), J7.3
unnamed: A1.12 (D9), U1.10 (S0)
unnamed: A1.13 (D10), U1.11 (S1)
unnamed: A1.19 (A0), D1.1 (K), R3.2, U2.1
unnamed: A1.27 (+5V), J7.1, R2.1, RV1.2, U1.24 (VCC)
unnamed: A1.30 (VIN), J2.3, R4.2, U2.8 (V+)
unnamed: C1.2, R1.2, R2.2, U2.3 (+)
unnamed: D2.2 (A), R4.1
unnamed: J1.1, J2.2
unnamed: J3.2, U1.9 (I0)
unnamed: J4.2, U1.8 (I1)
unnamed: J5.2, U1.7 (I2)
unnamed: J6.2, U1.6 (I3)
unnamed: R3.1, RV1.3, U1.1 (COM), U2.2 (-)

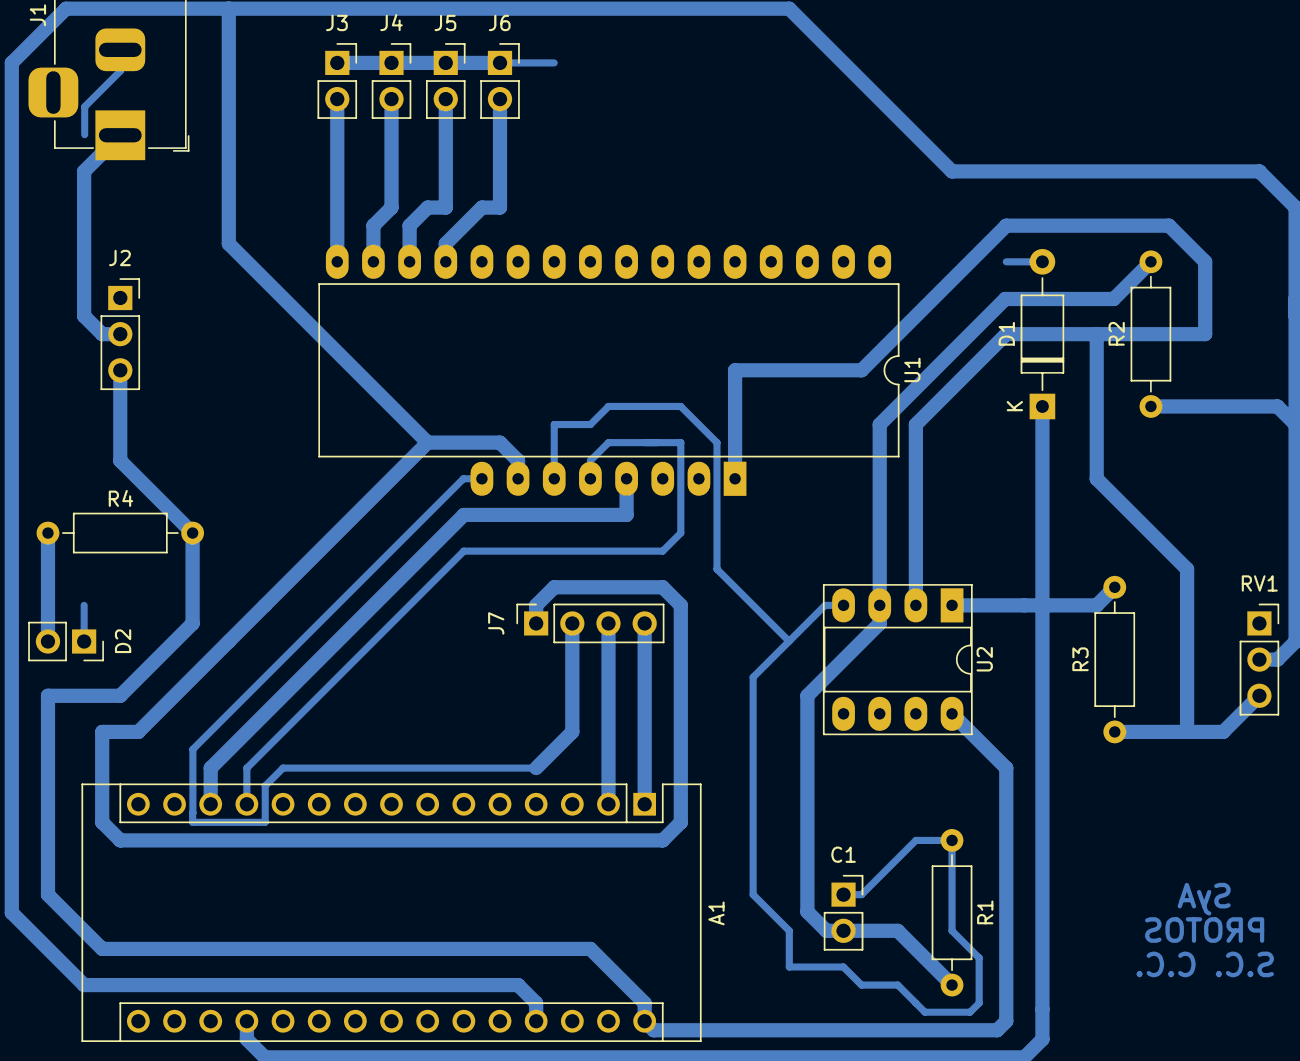
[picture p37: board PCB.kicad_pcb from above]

Board: 2 copper layers, 18 parts (0 on the bottom side), 16 nets.

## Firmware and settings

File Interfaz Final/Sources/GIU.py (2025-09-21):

import sys, time,threading
from Bluethoot import Bluethoot
from Map import MapHeat

from PyQt5.QtWidgets import QApplication, QMainWindow, QDialog,  QVBoxLayout
from PyQt5.QtGui import QPixmap
from PyQt5 import QtCore, QtWidgets
from PyQt5.QtCore import pyqtSignal
from PyQt5.uic import loadUi
from pyvistaqt import QtInteractor, BackgroundPlotter

class MainWindow(QMainWindow):
    def __init__(self):
        super(MainWindow, self).__init__()
        loadUi('diseno.ui', self)
	
        self.update = True

        self.dialog = Dialog() 
        self.Error = Dialog()

        self.Blue = Bluethoot()
        self.DataSensors = []

        self.Blue.SetConection(False)

        self.munon = MapHeat()
        self.munon.ObtainHeatValue2()
        self.munon.SetZone1(100)
        self.munon.change_neighbors(1211, 0, 200)
        self.munon.change_neighbors(1096, 0, 200)
        self.munon.change_neighbors(1256, 0, 300)
        self.munon.change_neighbors(1148, 0, 400)
        '''self.munon.change_neighbors(6077, 0, 1500)
        self.munon.change_neighbors(6909, 0, 4000)
        self.munon.change_neighbors(5597, 0, 4000)
        self.munon.change_neighbors(6554, 0, 5000)'''
        self.munon.AddMesh()
        self.munon.AddScalarBar()
        self.Plotter_data = self.munon.GetPlotter()

        #Widget de impresion 3D para desarrollo
        """vlayout = QtWidgets.QVBoxLayout()
        self.plotter = QtInteractor(self.frame_contenido)
        vlayout.addWidget(self.plotter.interactor)
        self.frame_contenido.setLayout(vlayout)
        self.plotter.add_mesh(self.Plotter_data, show_edges=True)
        self.plotter.reset_camera()"""

        #Botones de conexion
        self.bt_conectar.clicked.connect(self.control_bt_conectar)
        self.bt_conectar.clicked.connect(self.iniciar_hilo)
        self.bt_desconectar.clicked.connect(self.control_bt_desconectar)
        self.bt_reconectar.clicked.connect(self.control_bt_reconectar)
        self.bt_reconectar.clicked.connect(self.iniciar_hilo)
        
		# mover ventana
        self.frame_Logo.mouseMoveEvent = self.mover_ventana
        self.frame_control.mouseMoveEvent = self.mover_ventana

		#control barra de titulos
        self.bt_minimizar.clicked.connect(self.control_bt_minimizar)		
        self.bt_restaurar.clicked.connect(self.control_bt_normal)
        self.bt_maximizar.clicked.connect(self.control_bt_maximizar)
        self.bt_cerrar.clicked.connect(lambda: self.close())

        self.bt_restaurar.hide()

        #eliminar barra y de titulo - opacidad
        self.setAttribute(QtCore.Qt.WA_TranslucentBackground)
        self.setWindowFlag(QtCore.Qt.FramelessWindowHint)
        self.setWindowOpacity(1)

        #self.label_contenido.hide()
        
        #Imagen obejto 3D

    def control_bt_conectar(self):

        try:
            self.Blue.GenerateConection()
            self.Blue.SetConection(True)
           
        except OSError:
            if self.Blue.GetConection() == False:
                self.show_dialog()

    def control_bt_desconectar(self):

        self.Blue.SetConection(False)    

    def control_bt_reconectar(self):
            
        self.Blue.SetConection(True)

    def control_bt_minimizar(self):
        self.showMinimized()		

    def  control_bt_normal(self):
        self.setStyleSheet("background-color:#000000ff")
        self.setAutoFillBackground(True); 
        self.showNormal()		
        self.bt_restaurar.hide()
        self.bt_maximizar.show()

    def  control_bt_maximizar(self):
        self.setStyleSheet("background-color:blck")
        self.setAutoFillBackground(True); 
        self.showMaximized()
        self.bt_maximizar.hide()
        self.bt_restaurar.show()

	## mover ventana
    def mousePressEvent(self, event):
        self.clickPosition = event.globalPos()
                
    def mover_ventana(self, event):
        if self.isMaximized() == False:			
            if event.buttons() == QtCore.Qt.LeftButton:
                self.move(self.pos() + event.globalPos() - self.clickPosition)
                self.clickPosition = event.globalPos()
                event.accept()

        if event.globalPos().y() <=20:
            self.showMaximized()
        else:
            self.showNormal()

    def show_dialog(self):
        self.dialog.show()

    def show_Error(self):
        self.Error.show()

    def UpdateSensors(self):
        self.DataSensors = self.Blue.GetData()
        self.munon.change_neighbors(1211, self.DataSensors[0], 200)
        self.munon.change_neighbors(1096, self.DataSensors[1], 200)
        self.munon.change_neighbors(1256, self.DataSensors[2], 300)
        self.munon.change_neighbors(1148, self.DataSensors[3], 400)
        self.munon.AddMeshPlotterBackground()

    def ContinueUpdate(self):
        while self.update:
            self.UpdateSensors

    def iniciar_hilo(self):
        hilo = threading.Thread(target=self.mi_hilo)
        hilo.daemon = True
        hilo.start()

    def mi_hilo(self):
        print("Inicio del hilo")
        while(self.Blue.GetConection()):
            if(self.Blue.GetData() == []):
                break
            self.Blue.ObtainData()
            print(self.Blue.GetData())
            self.UpdateSensors()
            time.sleep(1)
        print("Fin del hilo")

class Dialog(QDialog):
    def __init__(self):
        QDialog.__init__(self)
        loadUi('diseno1.ui', self)
        self.setAttribute(QtCore.Qt.WA_TranslucentBackground)
        self.setWindowFlag(QtCore.Qt.FramelessWindowHint)
        self.setWindowOpacity(1)

        #control barra de titulos
        self.bt_minimizar2.clicked.connect(self.control_bt_minimizar)		
        self.bt_cerrar2.clicked.connect(lambda: self.close())

    def control_bt_minimizar(self):
        self.showMinimized()

    ## mover ventana
    def mousePressEvent(self, event):
        self.clickPosition = event.globalPos()

    def mover_ventana(self, event):
        if self.isMaximized() == False:			
            if event.buttons() == QtCore.Qt.LeftButton:
                self.move(self.pos() + event.globalPos() - self.clickPosition)
                self.clickPosition = event.globalPos()
                event.accept()

        if event.globalPos().y() <=20:
            self.showMaximized()
        else:
            self.showNormal()
		
if __name__ == "__main__":
    app = QApplication(sys.argv)
    miApp = MainWindow()
    miApp.show()
    sys.exit(app.exec_())





'''import sys, time,threading
from Bluethoot import Bluethoot
from Map import MapHeat

from PyQt5.QtWidgets import QApplication, QMainWindow, QDialog,  QVBoxLayout
from PyQt5.QtGui import QPixmap
from PyQt5 import QtCore, QtWidgets
from PyQt5.QtCore import pyqtSignal
from PyQt5.uic import loadUi
from pyvistaqt import QtInteractor, BackgroundPlotter

class MainWindow(QMainWindow):
    def __init__(self):
        super(MainWindow, self).__init__()
        loadUi('diseno.ui', self)
	
        self.update = True

        self.dialog = Dialog() 
        self.Error = Dialog()

        self.Blue = Bluethoot()
        self.DataSensors = []

        self.Blue.SetConection(False)

        self.munon = MapHeat()
        self.munon.ObtainHeatValue2()
        self.munon.SetZone1(100)
        self.munon.change_neighbors(6077, 0, 1500)
        self.munon.change_neighbors(6909, 0, 4000)
        self.munon.change_neighbors(5597, 0, 4000)
        self.munon.change_neighbors(6554, 0, 5000)
        self.munon.AddMesh()
        self.munon.AddScalarBar()
        self.Plotter_data = self.munon.GetPlotter()

        #Widget de impresion 3D
        vlayout = QtWidgets.QVBoxLayout()
        self.plotter = QtInteractor(self.frame_contenido)
        vlayout.addWidget(self.plotter.interactor)
        self.frame_contenido.setLayout(vlayout)
        self.plotter.add_mesh(self.Plotter_data, show_edges=True)
        self.plotter.reset_camera()

        #Botones de conexion
        self.bt_conectar.clicked.connect(self.control_bt_conectar)
        self.bt_conectar.clicked.connect(self.iniciar_hilo)
        self.bt_desconectar.clicked.connect(self.control_bt_desconectar)
        self.bt_reconectar.clicked.connect(self.control_bt_reconectar)
        self.bt_reconectar.clicked.connect(self.iniciar_hilo)
        
		# mover ventana
        self.frame_Logo.mouseMoveEvent = self.mover_ventana
        self.frame_control.mouseMoveEvent = self.mover_ventana

		#control barra de titulos
        self.bt_minimizar.clicked.connect(self.control_bt_minimizar)		
        self.bt_restaurar.clicked.connect(self.control_bt_normal)
        self.bt_maximizar.clicked.connect(self.control_bt_maximizar)
        self.bt_cerrar.clicked.connect(lambda: self.close())

        self.bt_restaurar.hide()

        #eliminar barra y de titulo - opacidad
        self.setAttribute(QtCore.Qt.WA_TranslucentBackground)
        self.setWindowFlag(QtCore.Qt.FramelessWindowHint)
        self.setWindowOpacity(1)

        #self.label_contenido.hide()
        
        
        #Imagen obejto 3D


    def control_bt_conectar(self):

        try:
            self.Blue.GenerateConection()
            self.label_contenido.show()
            self.Blue.SetConection(True)
            self.munon.TakeAScreenshot()
            self.pixmap = QPixmap('Toma_2.jpg')
            self.label_contenido.setPixmap(self.pixmap)
            
           
        except OSError:
            if self.Blue.GetConection() == False:
                self.show_dialog()
            

    def control_bt_desconectar(self):

        self.Blue.SetConection(False)    

    def control_bt_reconectar(self):
            
        self.Blue.SetConection(True)


    def control_bt_minimizar(self):
        self.showMinimized()		

    def  control_bt_normal(self):
        self.setStyleSheet("background-color:#000000ff")
        self.setAutoFillBackground(True); 
        self.showNormal()		
        self.bt_restaurar.hide()
        self.bt_maximizar.show()

    def  control_bt_maximizar(self):
        self.setStyleSheet("background-color:blck")
        self.setAutoFillBackground(True); 
        self.showMaximized()
        self.bt_maximizar.hide()
        self.bt_restaurar.show()

	## mover ventana
    def mousePressEvent(self, event):
        self.clickPosition = event.globalPos()
                
    def mover_ventana(self, event):
        if self.isMaximized() == False:			
            if event.buttons() == QtCore.Qt.LeftButton:
                self.move(self.pos() + event.globalPos() - self.clickPosition)
                self.clickPosition = event.globalPos()
                event.accept()

        if event.globalPos().y() <=20:
            self.showMaximized()
        else:
            self.showNormal()

    def show_dialog(self):
        
        self.dialog.show()

    def show_Error(self):
        
        self.Error.show()

    def UpdateSensors(self):
        self.DataSensors = Bluethoot.GetData()
        self.munon.change_neighbors(6077, self.DataSensors[0], 1500)
        self.munon.change_neighbors(6909, self.DataSensors[1], 4000)
        self.munon.change_neighbors(5597, self.DataSensors[2], 4000)
        self.munon.change_neighbors(6554, self.DataSensors[3], 5000)
        self.munon.change_neighbors(1211, self.DataSensors[0], 200)
        self.munon.change_neighbors(1096, self.DataSensors[1], 200)
        self.munon.change_neighbors(1256, self.DataSensors[2], 300)
        self.munon.change_neighbors(1148, self.DataSensors[3], 400)
        self.munon.AddMesh()
        self.munon.GetPlotterBackground()

    def ContinueUpdate(self):
        while self.update:
            self.UpdateSensors

    def iniciar_hilo(self):
        hilo = threading.Thread(target=self.mi_hilo)
        hilo.daemon = True
        hilo.start()
        print("llegamos")
        

    def mi_hilo(self):
        print("Inicio del hilo")
        while(self.Blue.GetConection()):
            if(self.Blue.GetData() == []):
                break
            self.Blue.ObtainData()
            print(self.Blue.GetData())
            time.sleep(1)
        print("Fin del hilo")
       

class Dialog(QDialog):
    def __init__(self):
        QDialog.__init__(self)
        loadUi('diseno1.ui', self)
        self.setAttribute(QtCore.Qt.WA_TranslucentBackground)
        self.setWindowFlag(QtCore.Qt.FramelessWindowHint)
        self.setWindowOpacity(1)

        #control barra de titulos
        self.bt_minimizar2.clicked.connect(self.control_bt_minimizar)		
        self.bt_cerrar2.clicked.connect(lambda: self.close())

    def control_bt_minimizar(self):
        self.showMinimized()

    ## mover ventana
    def mousePressEvent(self, event):
        self.clickPosition = event.globalPos()

    def mover_ventana(self, event):
        if self.isMaximized() == False:			
            if event.buttons() == QtCore.Qt.LeftButton:
                self.move(self.pos() + event.globalPos() - self.clickPosition)
                self.clickPosition = event.globalPos()
                event.accept()

        if event.globalPos().y() <=20:
            self.showMaximized()
        else:
            self.showNormal()


		
if __name__ == "__main__":
    app = QApplication(sys.argv)
    miApp = MainWindow()
    miApp.show()
    sys.exit(app.exec_())'''

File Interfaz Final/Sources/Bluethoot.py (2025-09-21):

import serial, time
import serial.tools.list_ports

class Bluethoot():
    def __init__(self):
        # Obtener la lista de todos los puertos seriales disponibles en el sistema
        self.available_ports = list(serial.tools.list_ports.comports())
        # Lista para almacenar los nombres de los dispositivos Bluetooth
        self.device_names = []
        # Lista para almacenar los puertos seriales utilizados por los dispositivos Bluetooth
        self.serial_ports = []
        #Puerto serial a usar 
        self.Port = ''
        #Lista con los datos
        self.Data = []
        #Conexion establecida
        self.Conection = True
        #Conexion serial
        self.ser = ''            

    def ObtainBluethootPorts(self):     
        # Iterar sobre los puertos seriales disponibles en el sistema
        for port in self.available_ports:
            # Si el puerto serial está asociado a un dispositivo Bluetooth, agregarlo a las listas
            if "Bluetooth" in port.description:
                self.device_names.append(port.description)
                self.serial_ports.append(port.device)
                #print("Dispositivo Bluetooth: {}".format(port.description))
                #print("Puerto Serial: {}".format(port.device))

        print("Nombres de dispositivos Bluetooth: {}".format(self.device_names))
        print("Puertos seriales utilizados por dispositivos Bluetooth: {}".format(self.serial_ports))

    def ObtainValidPort(self):
        #Iteración sobre los puertos seriales bluethoot hasta encontrar el que esta mandando los datos correctos
        for port in self.serial_ports:
            self.Port = port
            self.ser = serial.Serial(self.Port, 9600, timeout = 1)
            time.sleep(2)
            self.Datos = self.ser.readline().decode('utf-8')
            self.Data = self.Datos.split(" ")
            if self.Data[0] == "Sensor1:":
                break

    def ContinueConetion(self):
        #Ciclo infinito el cual mantiene la recepción de datos 
        while self.Conection:
            self.Datos = self.ser.readline().decode('utf-8')
            self.Data = self.Datos.split(" ")
            #print(self.Datos)
            #print(self.Data)
            time.sleep(2)

    def ObtainData(self):
        if self.Conection == True:
            #Obtención y separacion de datos
            self.Datos = self.ser.readline().decode('utf-8')
            self.Data = self.Datos.split(" ")
            #print(self.Datos)
            #print(self.Data)
            time.sleep(2)

    def SetConection(self, Conection = True):
        self.Conection = Conection

    def GetConection(self):
        return self.Conection

    def GenerateConection(self):
        self.ObtainBluethootPorts()
        self.ObtainValidPort()
        self.SetConection()
    
    def GetData(self):
        Dataout = []
        for i in self.Data:
            try:
                Datain = float(i)
                Dataout.append(Datain)
            except ValueError:
                continue
        return Dataout
    
    def GetDatos(self):
        return self.Datos



Blue = Bluethoot()
Blue.GenerateConection()
Blue.ObtainData()
print(Blue.GetData())
Blue.ContinueConetion()





'''import serial, time
import serial.tools.list_ports

class Bluethoot():
    def __init__(self):
        # Obtener la lista de todos los puertos seriales disponibles en el sistema
        self.available_ports = list(serial.tools.list_ports.comports())
        # Lista para almacenar los nombres de los dispositivos Bluetooth
        self.device_names = []
        # Lista para almacenar los puertos seriales utilizados por los dispositivos Bluetooth
        self.serial_ports = []
        #Puerto serial a usar 
        self.Port = ''
        #Lista con los datos
        self.Data = []
        #Conexion establecida
        self.Conection = True
        #Conexion serial
        self.ser = ''            

    def ObtainBluethootPorts(self):     
        # Iterar sobre los puertos seriales disponibles en el sistema
        for port in self.available_ports:
            # Si el puerto serial está asociado a un dispositivo Bluetooth, agregarlo a las listas
            if "Bluetooth" in port.description:
                self.device_names.append(port.description)
                self.serial_ports.append(port.device)
                #print("Dispositivo Bluetooth: {}".format(port.description))
                #print("Puerto Serial: {}".format(port.device))

        #print("Nombres de dispositivos Bluetooth: {}".format(self.device_names))
        #print("Puertos seriales utilizados por dispositivos Bluetooth: {}".format(self.serial_ports))

    def ObtainValidPort(self):
        #Iteración sobre los puertos seriales bluethoot hasta encontrar el que esta mandando los datos correctos
        for port in self.serial_ports:
            self.Port = port
            self.ser = serial.Serial(self.Port, 9600, timeout = 1)
            time.sleep(2)
            self.Datos = self.ser.readline().decode('utf-8')
            self.Data = self.Datos.split(" ")
            if self.Data[0] == "Sensor1: ":
                break

    def ContinueConetion(self):
        #Ciclo infinito el cual mantiene la recepción de datos 
        while self.Conection:
            self.Datos = self.ser.readline().decode('utf-8')
            self.Data = self.Datos.split(" ")
            #print(self.Datos)
            #print(self.Data)
            time.sleep(2)

    def ObtainData(self):
        if self.Conection == True:
            #Obtención y separacion de datos
            self.Datos = self.ser.readline().decode('utf-8')
            self.Data = self.Datos.split(" ")
            #print(self.Datos)
            #print(self.Data)
            time.sleep(2)

    def SetConection(self, Conection = True):
        self.Conection = Conection

    def GetConection(self):
        return self.Conection

    def GenerateConection(self):
        self.ObtainBluethootPorts()
        self.ObtainValidPort()
        self.SetConection()
    
    def GetData(self):
        Dataout = []
        for i in self.Data:
            try:
                Data = float(i)
                Dataout.append(Data)
            except ValueError:
                continue
        return Dataout
    
    def GetDatos(self):
        return self.Datos'''



'''Blue = Bluethoot()
Blue.GenerateConection()
Blue.ObtainData()
print(Blue.GetData())
Blue.ContinueConetion()'''
